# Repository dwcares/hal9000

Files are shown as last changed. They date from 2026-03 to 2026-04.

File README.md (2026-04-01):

# HAL9000 Voice Assistant

A voice assistant powered by OpenAI running on Particle microcontrollers. Press a button to talk, receive AI-generated spoken responses. Designed to fit inside the [Moebius Models 1:1 HAL9000 kit](https://www.amazon.com/Moebius-Models-HAL9000-Styrene-MOE20015/dp/B07SVCLLFW).

> "I'm sorry Dave, I'm afraid I can't do that."

## Overview

HAL9000 demonstrates bidirectional audio streaming between a Particle device (Photon/Argon) and a Node.js server. The server uses OpenAI's Whisper for speech-to-text, GPT for conversation, and TTS for speech synthesis.

## Hardware

A custom carrier PCB is available for clean assembly. See the [hardware folder](hardware/) for KiCad source files and manufacturing outputs.

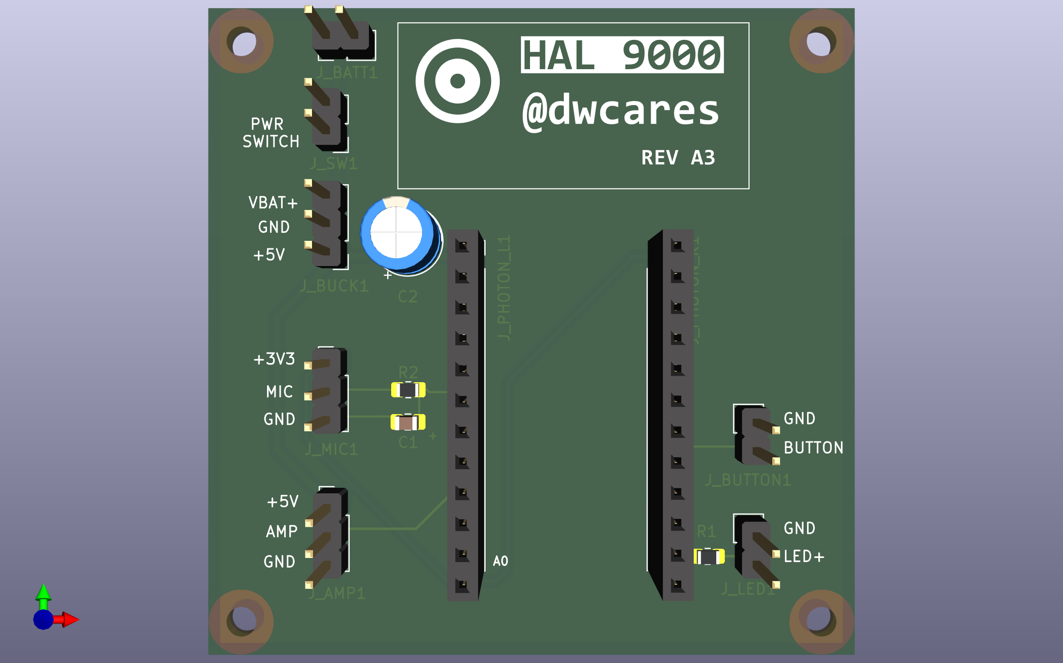
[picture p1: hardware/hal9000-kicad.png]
HAL9000 PCB


### Components

| Component | Description | Connection |
|---|---|---|
| Particle Photon | Wi-Fi MCU | Socket headers |
| MAX9814 Mic Module | Electret mic with AGC amp | J_MIC1 (3.3V/MIC/GND) |
| PAM8302A Amp Module | 2.5W Class-D mono amp | J_AMP1 (5V/AMP/GND) |
| 6mm Tactile Button | Push-to-talk | SW1 |
| 5mm LED | Status indicator | J_LED1 |
| Battery + Switch | Power input | J_BATT1, J_SW1 |
| Buck/Boost Converter | 5V regulated supply | J_BUCK1 |

### Quick Wiring (without PCB)

```
Particle Photon
┌─────────────────┐
│              A6 │──── Mic OUT (MAX9814)
│              A3 │──── Amp IN (PAM8302A)
│              D4 │──── Button ────┐
│             GND │────────────────┴── GND
│            3.3V │──── Mic VCC
│              5V │──── Amp VCC
│              D0 │──── LED+
└─────────────────┘
```

## Setup

### 1. Server Setup

```bash
cd server
npm install
```

Create a `.env` file:

```bash
cp .env.example .env
```

Edit `.env` with your credentials:

```
OPENAI_API_KEY=sk-your-key-here
PARTICLE_USERNAME=your-email@example.com
PARTICLE_PASSWORD=your-password
```

Start the server:

```bash
npm start
```

The server will:
- Login to Particle Cloud
- Publish its IP address for device discovery
- Listen for incoming device connections

### 2. Firmware Setup

Install the Particle CLI if you haven't:

```bash
npm install -g particle-cli
particle login
```

Install dependencies and flash:

```bash
cd firmware
particle library install
```

Compile and flash:

```bash
particle compile photon . --saveTo hal9000.bin
particle flash YOUR_DEVICE_NAME hal9000.bin
```

Or use Particle Workbench in VS Code.

> **Note:** No need to configure server IP - the device discovers it automatically via Particle Cloud!

## Usage

1. Power on the Particle device
2. Wait for the LED to indicate connection (solid on)
3. Press and hold the button to speak
4. Release the button when done
5. Wait for HAL's response through the speaker

## Configuration

### Server Options

| Environment Variable | Default | Description |
|---|---|---|
| `OPENAI_API_KEY` | - | Your OpenAI API key (required) |
| `PARTICLE_USERNAME` | - | Particle account email (for cloud discovery) |
| `PARTICLE_PASSWORD` | - | Particle account password |
| `PORT` | `5000` | Server port |
| `OPENAI_MODEL` | `gpt-4o` | Chat model |
| `OPENAI_VOICE` | `alloy` | TTS voice (alloy, echo, fable, onyx, nova, shimmer) |
| `SYSTEM_PROMPT` | (default) | AI personality prompt |
| `SAVE_RECORDINGS` | `false` | Save audio recordings to disk |

### Firmware Options

Edit the defines at the top of `hal9000.ino`:

```cpp
#define MIC_PIN      A6       // Microphone input
#define SPEAKER_PIN  A3       // Speaker output (DAC)
#define BUTTON_PIN   D4       // Push-to-talk button
#define LED_PIN      D0       // Status LED
#define SERVER_PORT  5000
```

## How Discovery Works

The server and device find each other automatically via Particle Cloud:

```
┌─────────────────┐                      ┌─────────────────┐
│  Node.js Server │                      │  Particle       │
│                 │                      │  Device         │
│ 1. Login to     │                      │                 │
│    Particle     │                      │ 3. Subscribe to │
│    Cloud        │                      │    server-ip    │
│                 │                      │    events       │
│ 2. Publish      │─── server-ip ───────►│                 │
│    server IP    │    (via cloud)       │ 4. Cache IP in  │
│                 │                      │    EEPROM       │
│ 5. Listen for   │◄── device-online ────│                 │
│    device-online│    (via cloud)       │ 5. Connect via  │
│    (republish)  │                      │    TCP          │
└─────────────────┘                      └─────────────────┘
```

- **First boot:** Device waits for server IP via cloud event
- **Subsequent boots:** Device uses cached IP for instant connect
- **Server restart:** Publishes new IP, devices update cache

## Dependencies

### Server
- [microstream-server](https://www.npmjs.com/package/microstream-server) - Audio streaming
- [particle-api-js](https://www.npmjs.com/package/particle-api-js) - Cloud discovery
- [openai](https://www.npmjs.com/package/openai) - AI services
- [dotenv](https://www.npmjs.com/package/dotenv) - Environment config

### Firmware
- [microstream](https://build.particle.io/libs/microstream) - Audio streaming library

## Troubleshooting

### No audio heard from speaker
- Check speaker wiring to DAC pin (A3 on Photon)
- Verify amplifier has power
- Check server console for "Playing response..." messages

### "Disconnected" status
- Verify server is running and reachable
- Check firewall allows port 5000
- Confirm device is on same network

### Transcription errors
- Speak clearly and close to microphone
- Check microphone wiring and amplifier gain
- Try adjusting `sampleRate` if audio quality is poor

## Architecture

```
┌─────────────────┐     TCP/WS      ┌─────────────────┐
│  Particle       │◄───────────────►│  Node.js        │
│  (microstream)  │                 │  (microstream-  │
│                 │                 │   server)       │
│  - Mic capture  │                 │                 │
│  - DAC playback │                 │  ┌───────────┐  │
│  - Button input │                 │  │ OpenAI    │  │
└─────────────────┘                 │  │ - Whisper │  │
                                    │  │ - GPT-4   │  │
                                    │  │ - TTS     │  │
                                    │  └───────────┘  │
                                    └─────────────────┘
```

## License

MIT License - see [LICENSE](LICENSE)

## Credits

Built with:
- [Microstream](https://github.com/dwcares/microstream) - Bidirectional audio streaming
- [OpenAI](https://openai.com) - AI services
- [Particle](https://particle.io) - IoT platform

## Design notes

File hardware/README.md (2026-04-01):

# HAL9000 Hardware

Custom carrier PCB for the HAL9000 voice assistant, designed in KiCad. This board is sized to mount inside the [Moebius Models 1:1 scale HAL9000 kit](https://www.amazon.com/Moebius-Models-HAL9000-Styrene-MOE20015/dp/B07SVCLLFW).

HAL9000 PCB

## Overview

This PCB provides a clean way to connect a Particle Photon to all the peripherals needed for the voice assistant:
- Microphone input with filtering
- Amplifier output for speaker
- Push-to-talk button
- Status LED
- Battery power with switch

## Files

| File | Description |
|---|---|
| `hal9000.kicad_pro` | KiCad project file |
| `hal9000.kicad_sch` | Schematic |
| `hal9000.kicad_pcb` | PCB layout |
| `hal9000_bom.csv` | Bill of materials |
| `manufacturing/` | Gerber files for fabrication |

## Bill of Materials

| Reference | Qty | Description | Notes |
|---|-----|---|---|
| U1 | 1 | Particle Photon | Main MCU |
| J_PHOTON_L1, J_PHOTON_R1 | 2 | 12-pin Female Header 2.54mm | Photon sockets |
| J_BATT1 | 1 | 2-pin Header | Battery input (VBAT+, GND) |
| J_SW1 | 1 | 2-pin Header | Power switch |
| J_BUCK1 | 1 | 3-pin Header | Buck converter (VBAT+, GND, +5V) |
| J_MIC1 | 1 | 3-pin Header | Mic module (+3V3, MIC, GND) |
| J_AMP1 | 1 | 3-pin Header | Amp module (+5V, AMP, GND) |
| J_LED1 | 1 | 2-pin Header | LED (GND, LED+) |
| SW1 | 1 | 6mm Tactile Button | Push-to-talk |
| R1 | 1 | 220Ω 0805 | LED current limiter |
| R2 | 1 | 1kΩ 0805 | Mic input filter |
| C1 | 1 | 10nF 0805 | Mic input filter |
| C2 | 1 | 470µF Electrolytic | 5V bulk capacitance |

## External Modules

These modules connect via headers:

| Module | Description | Header |
|---|---|---|
| MAX9814 | Electret mic with AGC amplifier | J_MIC1 |
| PAM8302A | 2.5W Class-D mono amplifier | J_AMP1 |
| Buck/Boost Converter | 5V regulated output | J_BUCK1 |

## Pin Mapping

| Signal | Photon Pin | Description |
|---|---|---|
| MIC | A6 | Microphone analog input |
| AMP | A3 (DAC) | Speaker DAC output |
| BUTTON | D4 | Push-to-talk input |
| LED | D0 | Status LED output |

## Power

The board supports battery power with an external switch:

```
Battery ──► J_BATT1 ──► J_SW1 (switch) ──► Buck Converter ──► J_BUCK1 (+5V out)
                                                                    │
                                                              Photon VIN
                                                                    │
                                                              Onboard 3.3V reg
```

- **5V rail**: Powers Photon (via VIN), amplifier module
- **3.3V rail**: Powers microphone module (from Photon regulator)

## Manufacturing

The `manufacturing/` folder contains Gerber files ready for PCB fabrication. Upload to your preferred PCB manufacturer (JLCPCB, PCBWay, OSH Park, etc.).

## Assembly Tips

1. Solder SMD components first (R1, R2, C1)
2. Install female headers for Photon (J_PHOTON_L1, J_PHOTON_R1)
3. Install remaining through-hole headers and button
4. Add electrolytic capacitor C2 (observe polarity)
5. Connect external modules via headers
6. Insert Particle Photon

## License

MIT License - see [LICENSE](../LICENSE)

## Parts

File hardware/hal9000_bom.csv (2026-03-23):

Reference | Quantity | Description | Manufacturer/Part | Notes
J_PHOTON_L1 | 1 | Conn_01x12 Female Header 2.54mm |  | Through-hole socket for Particle Photon (left row)
J_PHOTON_R1 | 1 | Conn_01x12 Female Header 2.54mm |  | Through-hole socket for Particle Photon (right row)
U1 | 1 | Particle Photon | Particle Photon Wi-Fi development board | Main MCU/module
J_BATT1 | 1 | Conn_01x02 Header 2.54mm |  | Battery connection
J_SW1 | 1 | Conn_01x02 Header 2.54mm |  | Power switch connection
J_BUCK1 | 1 | Conn_01x03 Header 2.54mm |  | Buck/boost converter connection
J_MIC1 | 1 | Conn_01x03 Header 2.54mm |  | Microphone module connection
J_AMP1 | 1 | Conn_01x03 Header 2.54mm |  | Amplifier module connection
J_LED1 | 1 | Conn_01x02 Header 2.54mm |  | LED connection
SW1 | 1 | 6mm Tactile Pushbutton THT |  | Push-to-talk button
LED1 | 1 | 5mm LED |  | Indicator LED
R1 | 1 | 220 Ohm Resistor 0805 |  | LED current limiting resistor
R2 | 1 | 1k Ohm Resistor 0805 |  | Mic input series/filter resistor
C1 | 1 | 10nF Capacitor 0805 |  | Mic input filter capacitor
C2 | 1 | 470uF Electrolytic Capacitor >=10V |  | 5V rail bulk capacitance
MIC1 | 1 | MAX9814 Microphone Amplifier Module | Analog electret mic breakout, VCC/OUT/GND | External mic module
AMP1 | 1 | PAM8302A Mono 2.5W Class-D Amplifier Module | 5V mono analog amp module | External amp module

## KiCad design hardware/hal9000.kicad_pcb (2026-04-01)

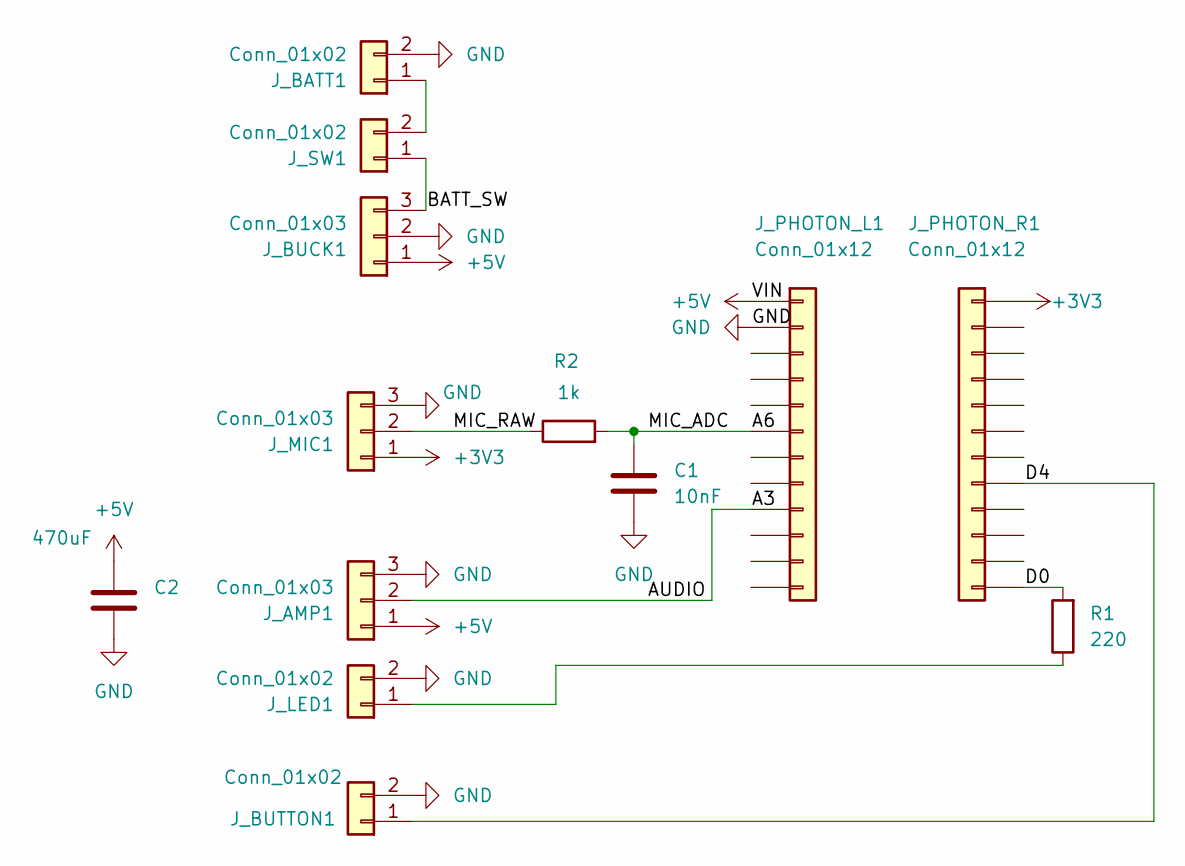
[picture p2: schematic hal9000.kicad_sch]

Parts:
C1: 10nF; C_0805_2012Metric_Pad1.18x1.45mm_HandSolder
C2: 470uF; CP_Radial_D6.3mm_P2.50mm
J_AMP1: Conn_01x03; PinHeader_1x03_P2.54mm_Vertical
J_BATT1: Conn_01x02; PinHeader_1x02_P2.54mm_Vertical
J_BUCK1: Conn_01x03; PinHeader_1x03_P2.54mm_Vertical
J_BUTTON1: Conn_01x02; PinHeader_1x02_P2.54mm_Vertical
J_LED1: Conn_01x02; PinHeader_1x02_P2.54mm_Vertical
J_MIC1: Conn_01x03; PinHeader_1x03_P2.54mm_Vertical
J_PHOTON_L1: Conn_01x12; PinSocket_1x12_P2.54mm_Vertical
J_PHOTON_R1: Conn_01x12; PinSocket_1x12_P2.54mm_Vertical
J_SW1: Conn_01x02; PinHeader_1x02_P2.54mm_Vertical
R1: 220; R_0805_2012Metric_Pad1.20x1.40mm_HandSolder
R2: 1k; R_0805_2012Metric_Pad1.20x1.40mm_HandSolder

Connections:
+3V3: J_MIC1.1, J_PHOTON_R1.1
+5V: C2.1, J_AMP1.1, J_BUCK1.1, J_PHOTON_L1.1
/A3: J_AMP1.2, J_PHOTON_L1.9
/A6: C1.2, J_PHOTON_L1.6, R2.2
/BATT_SW: J_BUCK1.3, J_SW1.1
/D0: J_PHOTON_R1.12, R1.2
/D4: J_BUTTON1.1, J_PHOTON_R1.8
/MIC_RAW: J_MIC1.2, R2.1
GND: C1.1, C2.2, J_AMP1.3, J_BATT1.2, J_BUCK1.2, J_BUTTON1.2, J_LED1.2, J_MIC1.3, J_PHOTON_L1.2
unnamed: J_BATT1.1, J_SW1.2
unnamed: J_LED1.1, R1.1

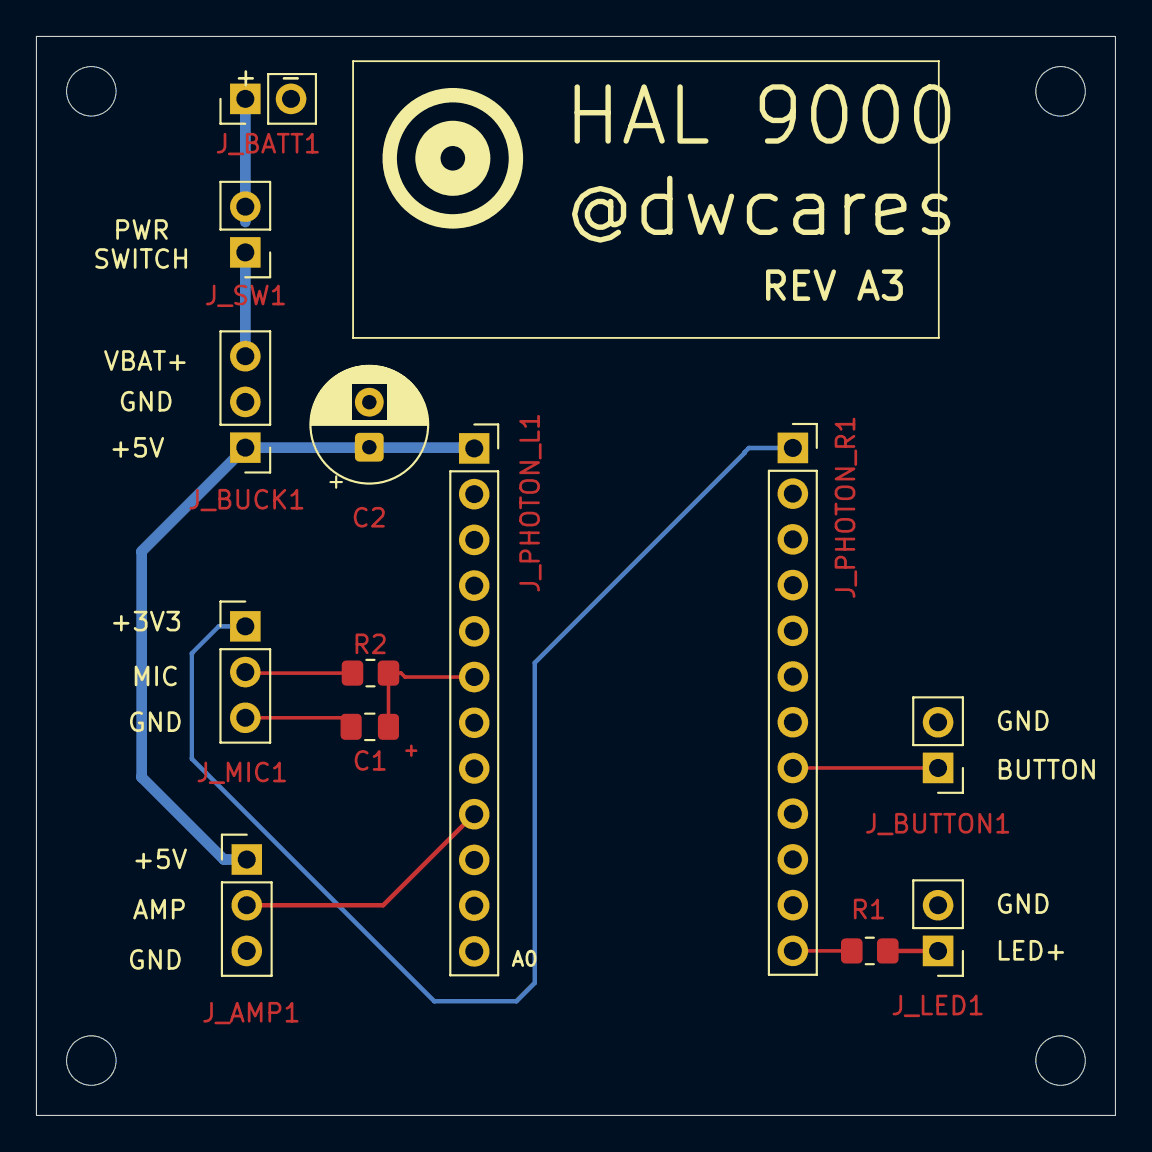
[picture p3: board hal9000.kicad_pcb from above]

Board: 2 copper layers, 59.9 x 59.9 mm, 13 parts (0 on the bottom side), 11 nets.

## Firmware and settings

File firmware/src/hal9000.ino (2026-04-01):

/*
 * HAL 9000 Voice Assistant
 *
 * Push-to-talk voice assistant using microstream and OpenAI.
 * Press and hold the button to talk, release to send.
 * LED indicates connection status.
 *
 * Hardware:
 *   - Microphone (with MAX4466 amp) on MIC_PIN
 *   - Speaker (with PAM8403 amp) on SPEAKER_PIN
 *   - Push button on BUTTON_PIN (active low)
 *   - Status LED on LED_PIN
 */

#include "Microstream.h"

// --- Hardware Pins ---
#define LED_PIN      D0       // Status LED (or use D7 for onboard)
#define BUTTON_PIN   D4       // Push-to-talk button
#define MIC_PIN      A6       // Microphone input (DAC pin, works as ADC)
#define SPEAKER_PIN  A3       // Speaker output (DAC: A3 on Photon, A6 on Argon)

// --- Server Configuration ---
#define SERVER_PORT  5000
#define SERVER_PATH  "/"
#define EEPROM_ADDR  0        // EEPROM address for cached IP

Microstream mic;

char serverHost[64] = "";     // Server IP from cloud discovery
bool serverConfigured = false;
bool buttonDown = false;
unsigned long lastStatusTime = 0;
unsigned long connectedSince = 0;

// --- EEPROM helpers for IP caching ---
void saveServerIP(const char* ip) {
  uint8_t len = strlen(ip);
  EEPROM.write(EEPROM_ADDR, len);
  for (uint8_t i = 0; i < len; i++) {
    EEPROM.write(EEPROM_ADDR + 1 + i, ip[i]);
  }
  Serial.printlnf("Cached server IP: %s", ip);
}

bool loadServerIP(char* ip, size_t maxLen) {
  uint8_t len = EEPROM.read(EEPROM_ADDR);
  if (len == 0 || len == 255 || len >= maxLen) return false;
  for (uint8_t i = 0; i < len; i++) {
    ip[i] = EEPROM.read(EEPROM_ADDR + 1 + i);
  }
  ip[len] = '\0';
  return true;
}

// --- Cloud event handler ---
void onServerIP(const char* event, const char* data) {
  Serial.printlnf("Received server IP: %s", data);

  // Only update if IP changed
  if (strcmp(serverHost, data) != 0) {
    strncpy(serverHost, data, sizeof(serverHost) - 1);
    saveServerIP(serverHost);

    if (!serverConfigured) {
      serverConfigured = true;
      startMicrostream();
    }
  }
}

// --- Callbacks ---
void onMicConnected() {
  connectedSince = millis();
  Serial.println("Connected to server");
}

void onMicDisconnected() {
  connectedSince = 0;
  Serial.println("Disconnected from server");
}

void onPlaybackStart() {
  Serial.println("Playing response...");
}

void onPlaybackEnd() {
  Serial.println("Playback done");
}

void startMicrostream() {
  MicrostreamConfig cfg;
  cfg.sampleRate = 16000;
  cfg.bitDepth = 16;
  cfg.micPin = MIC_PIN;
  cfg.speakerPin = SPEAKER_PIN;
  cfg.captureBufferSize = 8192;
  cfg.playbackBufferSize = 8192;

  Serial.printlnf("Connecting to %s:%d%s", serverHost, SERVER_PORT, SERVER_PATH);

  mic.begin(serverHost, SERVER_PORT, SERVER_PATH, cfg);
  mic.onConnected(onMicConnected);
  mic.onDisconnected(onMicDisconnected);
  mic.onPlaybackStart(onPlaybackStart);
  mic.onPlaybackEnd(onPlaybackEnd);
}

void setup() {
  Serial.begin(115200);
  delay(2000);
  Serial.println("--- HAL 9000 ---");

  pinMode(LED_PIN, OUTPUT);
  pinMode(BUTTON_PIN, INPUT_PULLUP);

  // Subscribe to server IP events
  Particle.subscribe("microstream/server-ip", onServerIP, MY_DEVICES);

  // Try to load cached IP
  if (loadServerIP(serverHost, sizeof(serverHost))) {
    Serial.printlnf("Using cached server IP: %s", serverHost);
    serverConfigured = true;
    startMicrostream();
  } else {
    Serial.println("No cached IP, waiting for server...");
  }

  // Announce we're online (triggers server to publish IP)
  Particle.publish("microstream/device-online", "", PRIVATE);
}

void loop() {
  if (serverConfigured) {
    mic.update();
  }

  // --- Push-to-talk button ---
  bool pressed = (digitalRead(BUTTON_PIN) == LOW);

  if (pressed && !buttonDown && serverConfigured && mic.isConnected()) {
    buttonDown = true;
    mic.startRecording();
    Serial.println("Recording...");
  }

  if (!pressed && buttonDown) {
    buttonDown = false;
    if (mic.isRecording()) {
      mic.stopRecording();
      Serial.println("Sent audio, waiting for response...");
    }
  }

  // --- LED feedback: on = connected, off = disconnected ---
  digitalWrite(LED_PIN, serverConfigured && mic.isConnected() ? HIGH : LOW);

  // --- Status ---
  if (millis() - lastStatusTime > 5000) {
    lastStatusTime = millis();
    if (!serverConfigured) {
      Serial.println("Status: WAITING FOR SERVER IP");
    } else if (mic.isConnected()) {
      Serial.printlnf("Status: CONNECTED | Uptime: %lus", (millis() - connectedSince) / 1000);
    } else {
      Serial.println("Status: DISCONNECTED");
    }
  }
}

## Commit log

2026-03-18 Initial commit: HAL 9000 voice assistant
    Voice assistant example using:
    - microstream (Particle library) for device firmware
    - microstream-server (npm) for Node.js backend
    - OpenAI for speech-to-text, chat, and text-to-speech
2026-03-18 Fix audio sample rate to match firmware capture rate
    Changed server audio config from 16000 Hz to 11200 Hz to match
    the actual capture rate from the Photon's ADC timing.
2026-03-18 Add Particle Cloud discovery for automatic server IP configuration
    Server:
    - Login to Particle Cloud on startup
    - Publish server IP via microstream/server-ip event
    - Subscribe to device-online events to republish IP
    Firmware:
    - Cache server IP in EEPROM for instant reconnect
    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
2026-03-18 Update README with Particle Cloud discovery setup
    - Document automatic server IP discovery via Particle Cloud
    - Add PARTICLE_USERNAME/PASSWORD to configuration
    - Add discovery flow diagram
    - Fix mic pin to A6
    - Remove manual SERVER_HOST configuration
2026-03-23 Add hardware PCB design for Moebius 1:1 HAL9000 model
    Add KiCad carrier PCB designed to mount inside the Moebius Models
    1:1 scale HAL9000 kit. Includes schematic, PCB layout, BOM, and
    manufacturing files. Update README with hardware section and PCB image.
    [hal9000.kicad_pcb, hal9000.kicad_sch, hal9000_bom.csv]
2026-03-27 hw: reva2 kicad files
    [hal9000.kicad_pcb, hal9000.kicad_sch]
2026-04-01 Update hw/fw to match reva2 and reva3 pushbutton at D4
    [hal9000.kicad_pcb, hal9000.kicad_sch]
